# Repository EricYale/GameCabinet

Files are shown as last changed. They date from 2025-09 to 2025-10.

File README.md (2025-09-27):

# GameCabinet
Raspberry Pi game cabinet, made for CPSC 3340 Creative Embedded Systems

## Required Materials
- [Raspberry Pi Zero 2 W, headerless](https://a.co/d/8KMoVYZ)
- [ESP-WROOM-32](https://a.co/d/iZ32vMO)
- SD card
- [Small touchscreen for Raspberry Pi Zero](https://a.co/d/8ljvQEd)
- [Short MtM microUSB cable](https://a.co/d/d5F0nlR)
- [Breadboard-layout PCBs](https://a.co/d/15BTbv4)
- [Joystick](https://a.co/d/iXG2HW7) (x2)
- Push button (x2)
- Flip switch (x2)

## Electronics Instructions

### Display

First, you have to solder your RasPi Zero to the small display. Solder all the pins; I found that it's much easier if you create an electrical connection between the pins and the holes before soldering by bending them slightly so they touch the copper rings. This makes it so that both the pins and the holes get heated and the solder can flow between them.

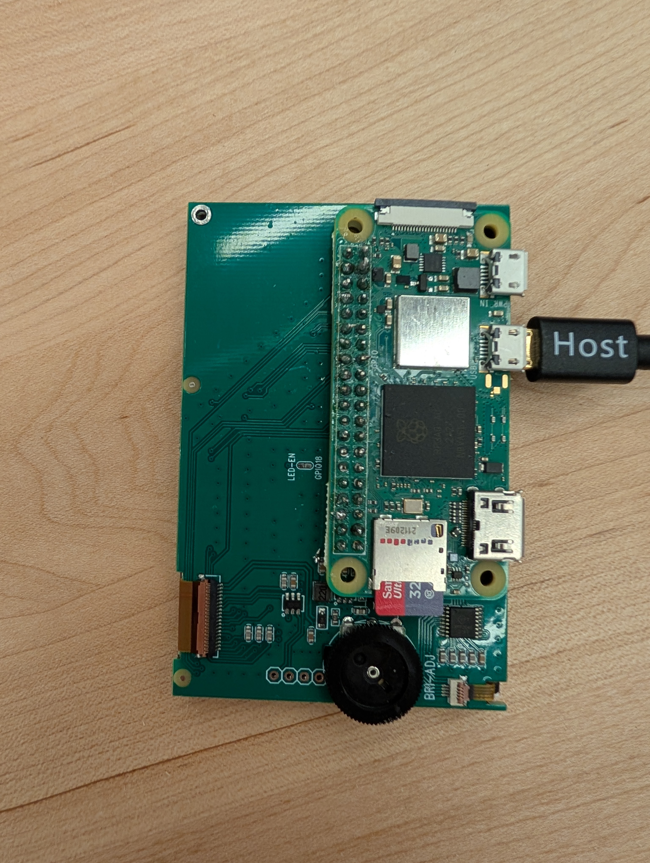
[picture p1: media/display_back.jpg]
Display solder


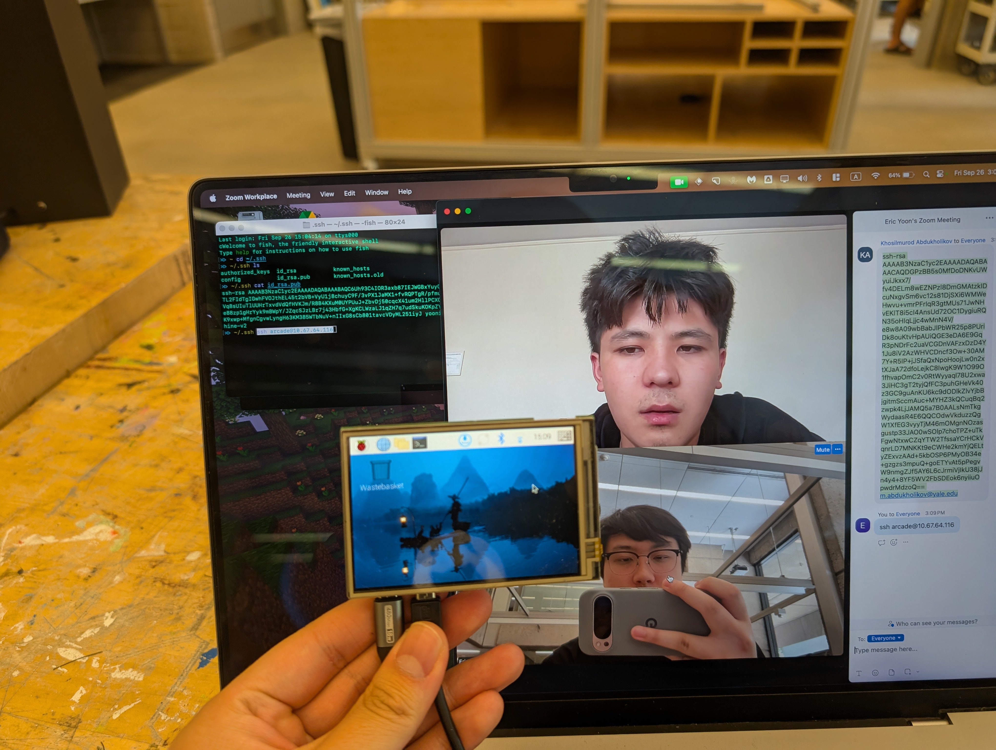
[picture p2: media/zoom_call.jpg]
Murad on Zoom


### Joystick
The joysticks you can get on Amazon come pre-installed with MtM headers. We need to remove these.

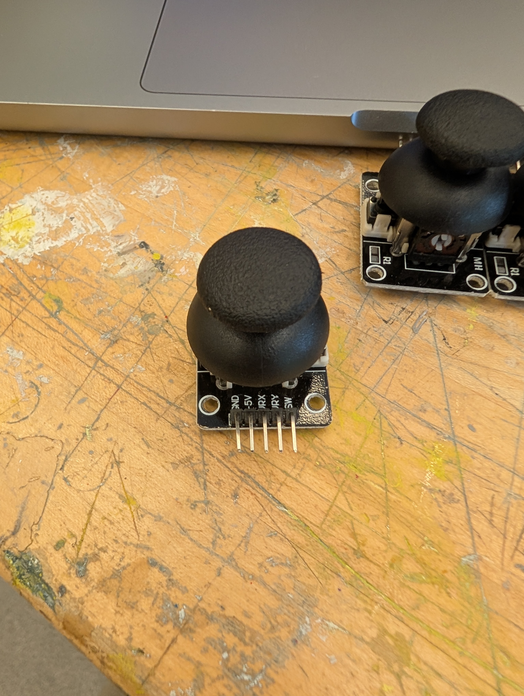
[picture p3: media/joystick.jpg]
Joystick headers that we need to remove


The best way to do this is to separate the headers by crushing them with some piliers, then applying heat and pulling them out one by one. Note that if you apply heat while pulling with the pliers, the pliers will act as a heat sink, so apply heat *then* apply pliers.

Then, you can solder your own wires to each of the four pins to be used: `GND`, `5V`, `VRY`, and `VRX`. Make sure to use long enough wires.

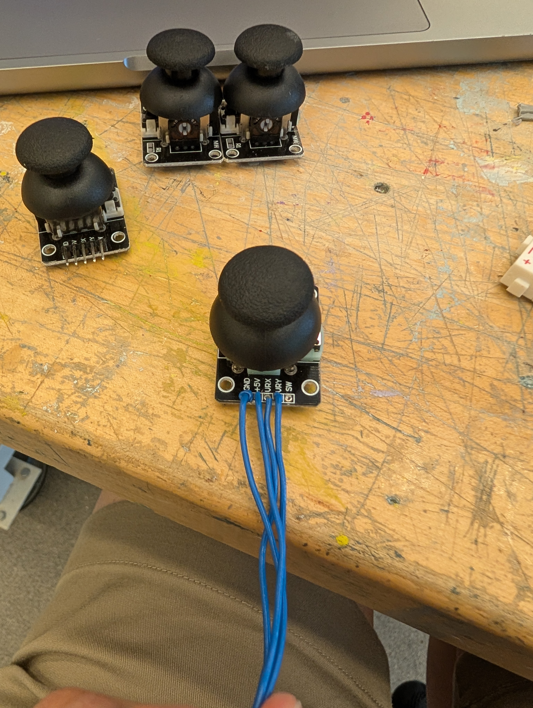
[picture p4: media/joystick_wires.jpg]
Joystick with wires


## 3D Printing Instructions

OnShape CAD available [here](https://cad.onshape.com/documents/6f27eda065649b08f7d7cace/w/1f5f86e878a776f90a9c0eb1/e/d24df1ab04ee5fd927d72df8).

Also see STL files in `/cad`

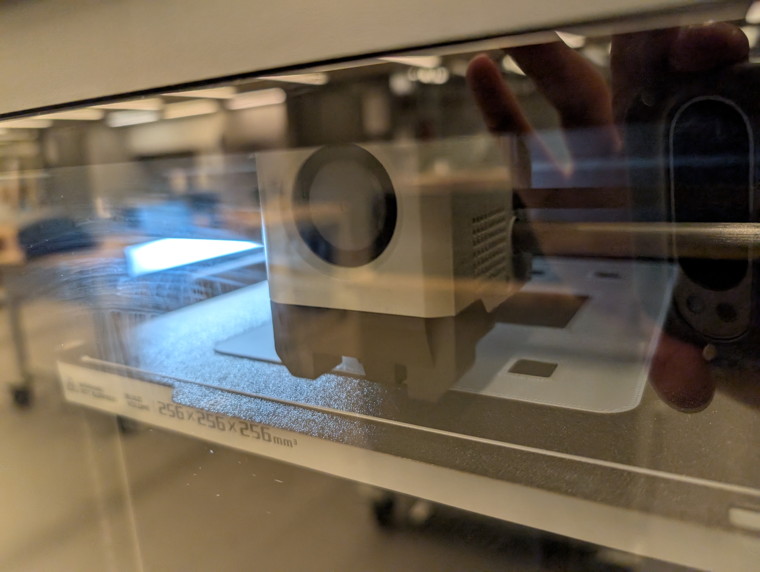
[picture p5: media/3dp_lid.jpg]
3D print in progress


## Pi Setup Instructions

Follow [this guide](https://www.raspberrypi.com/documentation/computers/getting-started.html) to install boot media onto an SD card for Raspberry Pi Zero.

On the SD card, follow [manufacturer's instructions](https://github.com/iUniker/Pi-Zero-3.5-Inch-Screen/tree/main) to add the drivers to the Pi, so it displays to the screen upon bootup.

At this point, you can boot up the Pi; if you need to register your device on the Yale network you can get the MAC address by doing `ifconfig`.

Once the Pi is connected to the Internet, you can get the IP address, SSH in, and add your SSH key.

You can then clone this repo, set Git to store your credentials, and log in with a Personal Access Token.

I also recommend adding an authorized SSH key.

## Technical Details

Sensor data is sent from the ESP32 to the Raspberry Pi over USB serial. Right now, data is being sent as ASCII (although in the future we could change this to raw binary data).

```
2048/2048/2048/2048/1/1/0/0
```
Where the numbers are delimited by slash (`/`). Each number represents:

1. Player 1 joystick X
2. Player 1 joystick Y
3. Player 2 joystick X
4. Player 2 joystick Y
5. Player 1 button
6. Player 2 button
7. Player 1 switch
8. Player 2 switch

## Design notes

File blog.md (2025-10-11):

# Game Cabinet

Demos:

[Gravity Game video](./media/space.mp4)

[Plant Growth video](./media/plant.mov)

[Asteroids video](./media/play_together.mov)

## **Creative Vision**

The initial concept was to create generative art pieces inspired by classic arcade games. That’s how we came up with **GameCabinet**, a two-player interactive box that can be used for collaborative art generation and playing games.

Two players sit facing each other with a small central display between them. Each has a joystick, a button, and a toggle switch. When connected via USB, the arcade menu loads and presents three modes: *Asteroids*, a collaborative *Plant Growth* simulation, and a shared *Gravity Planet* environment.

- **Asteroids**: a clone of the classic arcade game, as a proof-of-concept of how the form factor can be used for all sorts of games.
- **Plant Growth:** In this mode, two players collaborate to shape the direction, the buddings, and the flowers in a plant through the controls. Each play session results in a unique creation.
- **Gravity Planet:** Players collaborate to simulate asteroids forming rings around the two planets. Joysticks are used to generate asteroids, while with the buttons, the gravity of the two planets can be adjusted.

---

## **Technical Overview**

For the project, Eric bought a **Raspberry Pi Zero 2 W** and a **mini-screen.** **Raspberry Pi Zero 2 W** serves as the main compute module; while it has less computing power, its small form factor makes it ideal for this project. It connects via USB serial to an **ESP-WROOM-32 microcontroller**, which reads all sensor data from the input hardware and transmits it to the Pi via serial.

### **Hardware Components**

Each player’s control panel includes:

- Analog joystick
- Push button
- Toggle switch

Additional components:

- Pi Zero Display Shield
- ESP32

On the Pi, the application parses data from the inputs and converts them into real-time logic for interaction.

---

## Hardware Details

We decided to solder each component onto a protoboard so the device could handle light impacts (from being carried around in a backpack, lightly battered when one player rage-quits, etc). Some steps in the process of fabricating the electronics:

1. Every pin on the RasPi Zero W was soldered directly onto the pins of the mini display.
2. Pre-installed male headers were removed from the joysticks, and wires were soldered on.
3. Input peripherals and ESP32 were soldered to proto board.

You can view more detailed instructions for making your own Game Cabinet [in our README](./README.md).

## Enclosure

The enclosure was designed in OnShape and 3D printed. To facilitate easy modeling, we were able to find models of our standard components (joystick, switch, button) online; we imported these models and designed around their dimensions. Some iteration was still necessary, but we were able to get a satisfactory enclosure fabricated in just 2 print jobs.

STL files are included in [here](./cad/).

---

## **Modes of Interaction**

As mentioned above, we implemented three interaction modes that the user can select from the Arcade Menu.

### **1. Asteroids**

This mode recreates the classic asteroids game in the arcade box.

- each joystick controls a spaceship’s movement on screen.
- button presses fire projectiles to destroy incoming asteroids.
- switches toggle thrusts the spaceship.

### **2. Growth**

The **Growth** game is a collaborative, rather than competitive, experience. It’s supposed to encourage communication between players while creating a zen atmosphere. When you’re done playing, you can pause and enjoy the ephemeral and unique creation you’ve made with your partner.

- the collaborative joystick positions determine the direction that the plant grows. Players need to be on the same page about which direction they want to go!
- button presses either creates buds (P1), or adds flowers (P2)
- switches either pause or resume the game. Both players need to agree to resume the game for the simulation to tick.

As the plant keeps growing, the earlier trunk of the plant keeps getting thicker. After the plant goes out of the screen, the earliest bud starts growing. The buds are added to the FIFO stack.

### 3. Gravity Planet

This mode explores how two players acting independently can lead to emergent behavior; and how when those two players collaborate, they can achieve even more complex behavior. We were inspired by classic physics-based games and simulations. We expect players to find fascination in our simulation and organically come up with goals (make all the balls travel in a perfect ellipse, etc). To do this, though, they have to communicate with their partner across the device.

## **Challenges & Solutions**

- **Programming:** We *vibecoded* the modes together. Because the Raspberry Pi Zero’s performance was limited, we couldn’t program directly on the Pi. Instead, we’d write code locally, push it to Git, and then hope it ran correctly after each commit. Luckily, we were able to run the simulations on our laptops before pushing code to the Pi, albeit with keyboard/mouse input rather than control surface input. The LLM originally had lots of trouble conceptualizing our serial communication; to alleviate this, we wrote an LLMS.md file along with hand-written ESP32 deserialization example code.
- **Analog Input on Digital Hardware:** The Raspberry Pi’s GPIO pins can’t read analog signals directly, so we offloaded sensor reading to the ESP32, which forwards processed data over serial.

Below are some of the photos from the process of completing the project.

3D printed lid

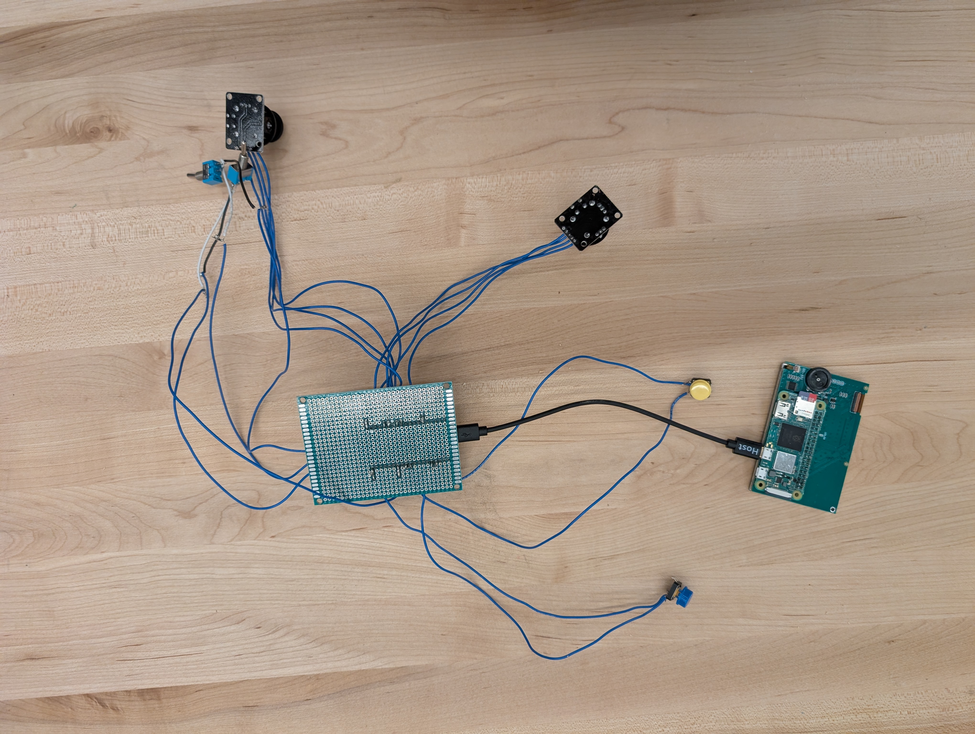
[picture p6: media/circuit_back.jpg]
Circuit back


Display back

Joystick

Joystick wires

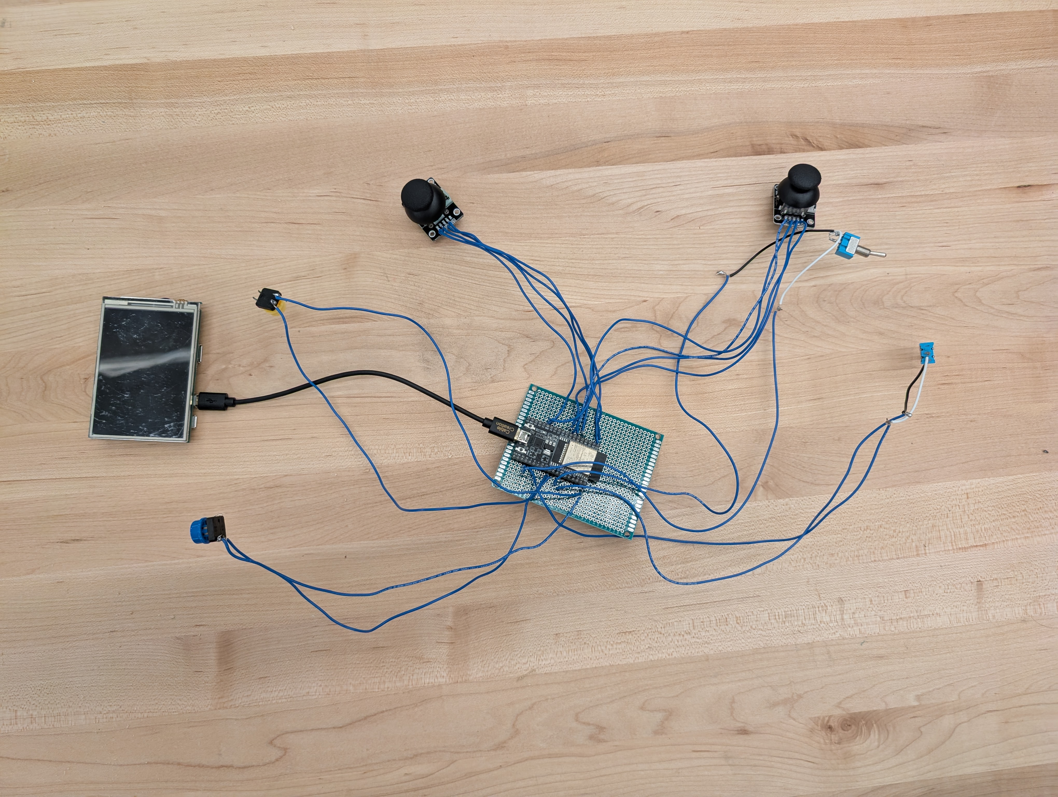
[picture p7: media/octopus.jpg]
Octopus


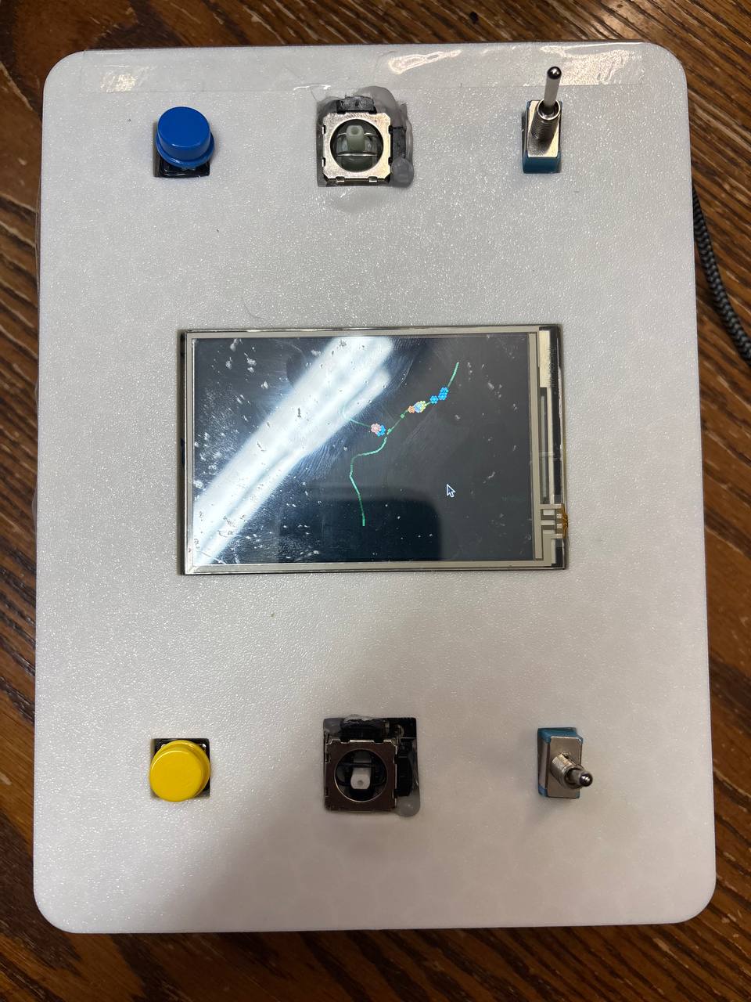
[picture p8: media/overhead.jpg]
Overhead


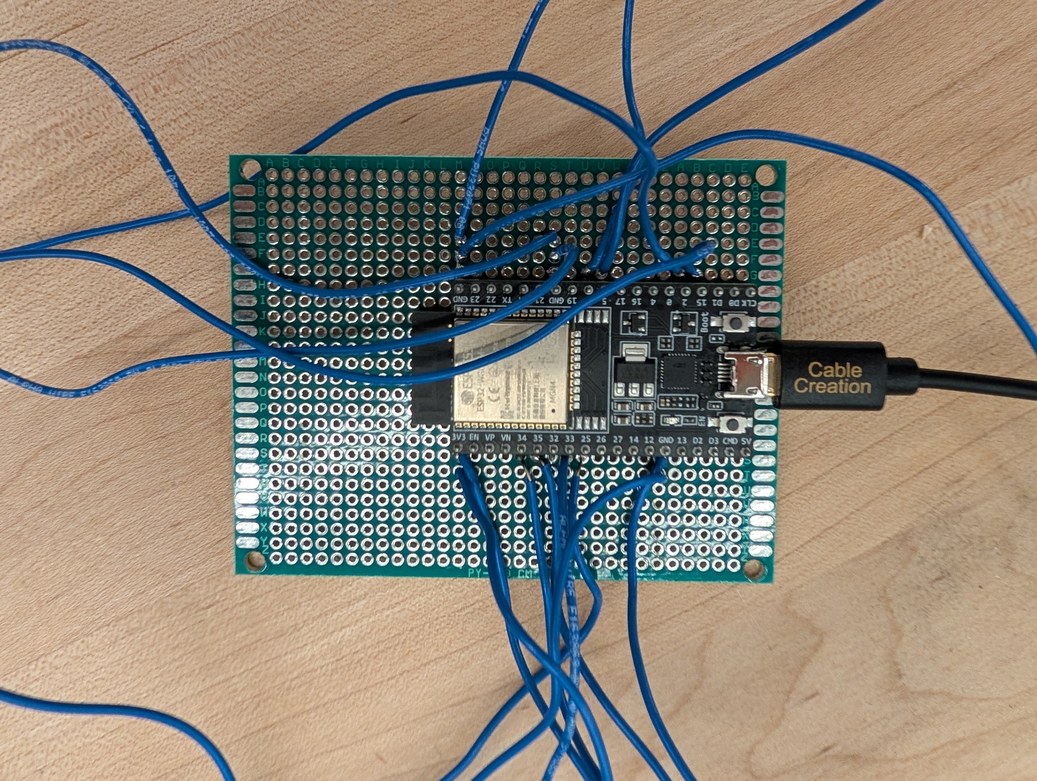
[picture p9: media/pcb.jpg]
PCB


Zoom call

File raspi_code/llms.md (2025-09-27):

# Notes to LLMs

You are writing code for a physical embedded system. The embedded system is running on a Raspberry Pi Zero 2 W, connected via USB to an ESP32, which reads sensor data and sends it using serial to the Raspberry Pi.

The device looks like a mini arcade cabinet, where two players sit facing each other, with the device in the middle. Each player has a joystick (X and Y axis), a momentary push button, and a toggle switch. There is a screen in the middle of the arcade cabinet which both players will look at; this means it's important to make sure any graphics are orientation-agnostic (so it's not upside down for one player).

The ESP32 communicates to the Raspberry Pi via serial. It sends numbers (which are ASCII strings and need to be parsed to ints). These numbers are slash-deliminated like so:

```
2048/2048/2048/2048/1/1/0/0
```
Each number represents:

1. Player 2 joystick Y (NOTE: this is inoperative, so your program must not use this input)
2. Player 2 joystick X
3. Player 1 joystick Y (NOTE: this is inoperative, so your program must not use this input)
4. Player 1 joystick X
5. Player 1 button (1 for unpressed, 0 for pressed)
6. Player 2 button (1 for unpressed, 0 for pressed)
7. Player 1 switch (0 for DOWN, 1 for UP)
8. Player 2 switch (1 for DOWN, 0 for UP; note that this is reverse of P1)

Your task is to code the game or application that I specify. You can view a demo of parsing the serial data from the ESP32 in esp32_input_demo.py. Your game should run full-screen on the Raspberry Pi when I start the program with `python3 <...>.py`. Please use pygame for your game; assume that the dependency is already installed.

At the top of your file, write down a high-level overview (2 paragraphs) of the game I described, and any implementation details that are not already specified in llms.md. Please do not leave any other comments in the code, because I am very good at reading code without comments.

Do not run any terminal commands to install packages; I will do these manually. Also please work ONLY in the file I specify. Do not create any python virtual environments.

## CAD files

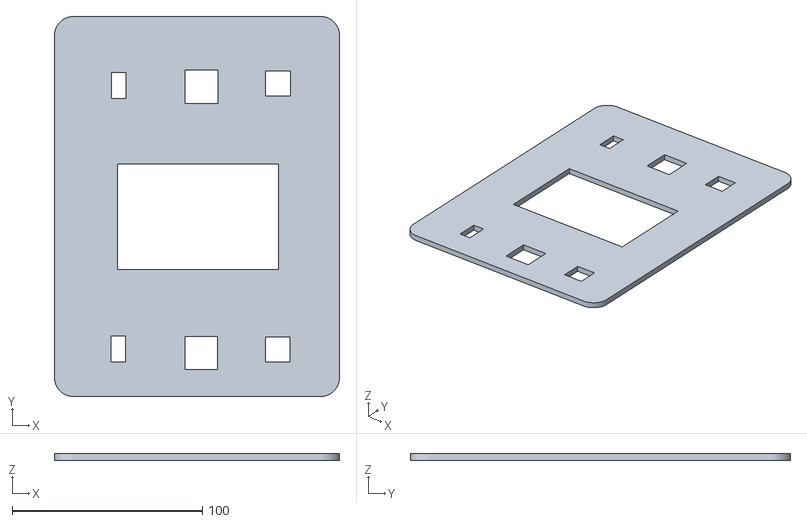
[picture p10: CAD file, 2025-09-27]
cad/lid.stl
150.0 x 200.0 x 3.50

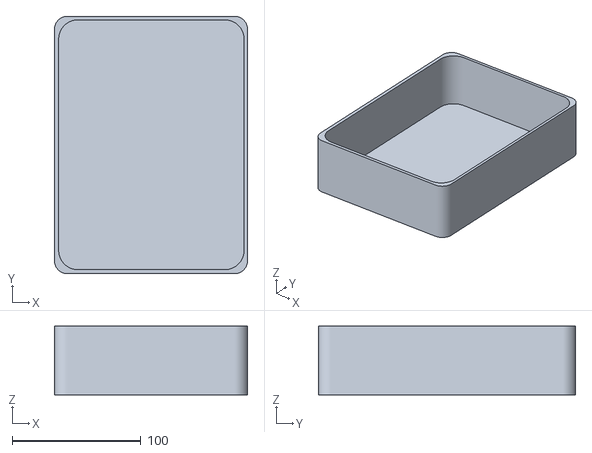
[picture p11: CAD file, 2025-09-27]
cad/housing.stl
150.0 x 200.0 x 53.5

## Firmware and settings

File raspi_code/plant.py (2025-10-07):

# Symbiosis Garden is a meditative cooperative art experience where two players
# nurture a shared digital plant through synchronized interaction. Players use
# their joysticks to collectively guide the plant's growth direction - when both
# players point in similar directions, the plant grows that way, but if they
# disagree, the plant pauses until they find harmony. This creates a natural
# dialogue through movement. The buttons allow players to add colorful flowers
# along the plant's stem, while the toggle switches control the growth state -
# both players must agree to grow (switches up) or rest (switches down).

# The implementation uses particle systems for organic, flowing growth patterns
# and a color palette that shifts based on the players' harmony level. The plant
# grows as a series of connected segments, each influenced by the average joystick
# input when there's agreement. Flowers bloom as animated sprites at button press
# locations, with colors cycling through a natural spectrum. The background
# subtly shifts to reflect the garden's health and the players' collaboration,
# creating a living, breathing digital ecosystem that responds to human connection.

import pygame
import serial
import math
import random
import time

pygame.init()

# Colors
DEEP_GREEN = (20, 60, 30)
SOFT_GREEN = (50, 120, 60)
BRIGHT_GREEN = (80, 200, 100)
FLOWER_COLORS = [
    (255, 100, 150),  # Pink
    (255, 200, 50),   # Yellow
    (150, 100, 255),  # Purple
    (255, 150, 100),  # Orange
    (100, 200, 255),  # Blue
    (255, 255, 150),  # Light Yellow
]
STEM_COLOR = (60, 140, 80)
BACKGROUND_BASE = (15, 25, 20)

# Screen setup
info = pygame.display.Info()
SCREEN_WIDTH, SCREEN_HEIGHT = info.current_w, info.current_h
SCALE_FACTOR = min(SCREEN_WIDTH / 1280.0, 1.0)
screen = pygame.display.set_mode((SCREEN_WIDTH, SCREEN_HEIGHT), pygame.FULLSCREEN)
pygame.display.set_caption("Symbiosis Garden")

# Serial setup
try:
    ser = serial.Serial("/dev/ttyUSB0", 115200, timeout=0.01)
except serial.SerialException:
    ser = None
    print("Serial port not found. Running with keyboard controls.")

class PlantSegment:
    def __init__(self, x, y, angle, length, base_thickness=None):
        self.start_pos = pygame.Vector2(x, y)
        self.angle = angle
        self.length = length
        self.end_pos = self.start_pos + pygame.Vector2(
            math.cos(math.radians(angle)) * length,
            math.sin(math.radians(angle)) * length
        )
        self.base_thickness = base_thickness if base_thickness else 8 * SCALE_FACTOR
        self.thickness = self.base_thickness
        self.age = 0
        self.growth_animation = 0
        self.segment_index = 0
        
    def update(self, dt):
        self.age += dt
        if self.growth_animation < 1.0:
            self.growth_animation = min(1.0, self.growth_animation + dt * 2)
            
    def update_thickness(self, total_segments):
        # Older segments (lower index) get thicker as plant grows
        age_factor = max(0.5, 1.0 - (self.segment_index / max(1, total_segments)))
        thickness_boost = (total_segments - self.segment_index) * 0.5 * SCALE_FACTOR
        self.thickness = self.base_thickness + thickness_boost * age_factor
            
    def draw(self, surface):
        if self.growth_animation <= 0:
            return
            
        current_length = self.length * self.growth_animation
        current_end = self.start_pos + pygame.Vector2(
            math.cos(math.radians(self.angle)) * current_length,
            math.sin(math.radians(self.angle)) * current_length
        )
        
        # Draw segment with slight transparency for organic feel
        color_intensity = 200 + int(55 * math.sin(self.age * 0.5))
        color = (
            max(0, min(255, STEM_COLOR[0] + color_intensity - 200)),
            max(0, min(255, STEM_COLOR[1] + color_intensity - 200)),
            max(0, min(255, STEM_COLOR[2] + color_intensity - 200))
        )
        
        pygame.draw.line(surface, color, self.start_pos, current_end, int(self.thickness))

class Flower:
    def __init__(self, x, y, color):
        self.pos = pygame.Vector2(x, y)
        self.color = color
        self.size = 0
        self.max_size = random.uniform(15, 25) * SCALE_FACTOR
        self.bloom_speed = random.uniform(3, 5)
        self.sway_offset = random.uniform(0, math.pi * 2)
        self.age = 0
        self.petals = random.randint(5, 8)
        
    def update(self, dt):
        self.age += dt
        if self.size < self.max_size:
            self.size = min(self.max_size, self.size + self.bloom_speed * dt)
            
    def draw(self, surface):
        if self.size <= 0:
            return
            
        # Gentle swaying
        sway = math.sin(self.age * 2 + self.sway_offset) * 2
        current_pos = self.pos + pygame.Vector2(sway, 0)
        
        # Draw petals
        for i in range(self.petals):
            angle = (i / self.petals) * 2 * math.pi
            petal_pos = current_pos + pygame.Vector2(
                math.cos(angle) * self.size * 0.6,
                math.sin(angle) * self.size * 0.6
            )
            pygame.draw.circle(surface, self.color, petal_pos, int(self.size * 0.4))
            
        # Draw center
        center_color = tuple(max(0, min(255, c + 50)) for c in self.color)
        pygame.draw.circle(surface, center_color, current_pos, int(self.size * 0.3))

class Bud:
    def __init__(self, x, y, segment_index):
        self.pos = pygame.Vector2(x, y)
        self.segment_index = segment_index
        self.size = 0
        self.max_size = 8 * SCALE_FACTOR
        self.growth_speed = 4
        self.age = 0
        self.used = False
        self.pulse_offset = random.uniform(0, math.pi * 2)
        
    def update(self, dt):
        self.age += dt
        if self.size < self.max_size and not self.used:
            self.size = min(self.max_size, self.size + self.growth_speed * dt)
            
    def draw(self, surface):
        if self.size <= 0:
            return
            
        # Pulsing green bud
        pulse = 0.8 + 0.2 * math.sin(self.age * 3 + self.pulse_offset)
        if self.used:
            pulse *= 0.3  # Dim when used
            
        bud_color = tuple(int(c * pulse) for c in BRIGHT_GREEN)
        pygame.draw.circle(surface, bud_color, self.pos, int(self.size))
        
        # Small highlight
        highlight_pos = self.pos + pygame.Vector2(-2, -2)
        highlight_color = tuple(min(255, int(c * 1.5)) for c in bud_color)
        pygame.draw.circle(surface, highlight_color, highlight_pos, int(self.size * 0.4))

class HarmonyParticle:
    def __init__(self, x, y):
        self.pos = pygame.Vector2(x, y)
        self.vel = pygame.Vector2(
            random.uniform(-50, 50) * SCALE_FACTOR,
            random.uniform(-100, -20) * SCALE_FACTOR
        )
        self.life = 1.0
        self.decay_rate = random.uniform(0.5, 1.0)
        self.size = random.uniform(2, 6) * SCALE_FACTOR
        
    def update(self, dt):
        self.pos += self.vel * dt
        self.life -= self.decay_rate * dt
        self.vel.y += 20 * dt  # Slight gravity
        
    def draw(self, surface):
        if self.life <= 0:
            return
        alpha = int(255 * self.life)
        color = (*BRIGHT_GREEN, alpha)
        
        # Create surface with per-pixel alpha
        particle_surf = pygame.Surface((int(self.size * 2), int(self.size * 2)), pygame.SRCALPHA)
        pygame.draw.circle(particle_surf, color, (int(self.size), int(self.size)), int(self.size))
        surface.blit(particle_surf, (self.pos.x - self.size, self.pos.y - self.size), special_flags=pygame.BLEND_ALPHA_SDL2)

def calculate_joystick_direction_and_speed(p1_x, p2_x):
    """Calculate growth direction and speed from average joystick input"""
    # Convert to -1 to 1 range
    p1_normalized = (p1_x - 2048) / 2048.0
    p2_normalized = (p2_x - 2048) / 2048.0
    
    # Calculate average direction
    avg_direction = (p1_normalized + p2_normalized) / 2
    
    # Speed based on magnitude of average direction
    speed = abs(avg_direction)
    
    # Direction in degrees (convert from -1,1 to angle change)
    angle_change = avg_direction * 45  # Max 45 degrees per growth step
    
    return angle_change, speed

def main():
    clock = pygame.time.Clock()
    running = True
    last_time = time.time()
    
    # Plant state
    plant_segments = []
    flowers = []
    buds = []
    harmony_particles = []
    current_growth_point = None  # Tracks where we're currently growing from
    
    # Growth parameters
    plant_base_x = SCREEN_WIDTH // 2
    plant_base_y = SCREEN_HEIGHT - 100 * SCALE_FACTOR
    current_angle = -90  # Start growing upward
    segment_length = 25 * SCALE_FACTOR
    
    # Game state
    growth_active = False
    background_pulse = 0.0
    growth_frame_counter = 0
    frames_per_growth = 5  # Grow every 5 frames for slower growth
    
    # Input states
    p1_button_pressed = False
    p2_button_pressed = False
    p1_switch_state = 0
    p2_switch_state = 1
    
    # Add initial root segment
    root_segment = PlantSegment(plant_base_x, plant_base_y, current_angle, segment_length)
    root_segment.growth_animation = 1.0
    root_segment.segment_index = 0
    plant_segments.append(root_segment)
    current_growth_point = root_segment
    
    while running:
        current_time = time.time()
        dt = current_time - last_time
        last_time = current_time
        
        # Handle events
        for event in pygame.event.get():
            if event.type == pygame.QUIT:
                running = False
            if event.type == pygame.KEYDOWN:
                if event.key == pygame.K_ESCAPE:
                    running = False
        
        # Read serial input
        p1_joy_x, p2_joy_x = 2048, 2048  # Default neutral
        p1_button, p2_button = 1, 1      # Default unpressed
        p1_switch, p2_switch = 0, 1      # Default states
        
        if ser:
            while ser.in_waiting:
                try:
                    line = ser.readline().decode('utf-8').rstrip()
                    if line:
                        values = line.split("/")
                        if len(values) == 8:
                            p1_joy_x = int(values[1])
                            p2_joy_x = int(values[3])
                            p1_button = int(values[4])
                            p2_button = int(values[5])
                            p1_switch = int(values[6])
                            p2_switch = int(values[7])
                except (ValueError, IndexError):
                    pass
        else:
            # Keyboard fallback for testing
            keys = pygame.key.get_pressed()
            # More responsive keyboard controls
            if keys[pygame.K_a]: p1_joy_x = 500   # Left
            if keys[pygame.K_d]: p1_joy_x = 3500  # Right
            if keys[pygame.K_LEFT]: p2_joy_x = 500   # Left
            if keys[pygame.K_RIGHT]: p2_joy_x = 3500 # Right
            if keys[pygame.K_SPACE]: p1_button = 0
            if keys[pygame.K_RETURN]: p2_button = 0
        
        # Calculate joystick direction and speed from average
        angle_change, growth_speed = calculate_joystick_direction_and_speed(p1_joy_x, p2_joy_x)
        
        # Check if both players have switches in grow position
        # P1 switch: 1 = UP (grow), 0 = DOWN (pause)
        # P2 switch: 0 = UP (grow), 1 = DOWN (pause) - reversed!
        growth_active = (p1_switch == 1 and p2_switch == 0)
        
        # Handle differentiated button functions
        if plant_segments:
            tip_segment = plant_segments[-1]
            tip_pos = tip_segment.end_pos
            
            # Player 1: Plant flowers
            if p1_button == 0 and not p1_button_pressed:
                color = random.choice(FLOWER_COLORS)
                flowers.append(Flower(tip_pos.x, tip_pos.y, color))
                # Add harmony particles
                for _ in range(5):
                    harmony_particles.append(HarmonyParticle(tip_pos.x, tip_pos.y))
                p1_button_pressed = True
            elif p1_button == 1:
                p1_button_pressed = False
                
            # Player 2: Create buds (new growth points)
            if p2_button == 0 and not p2_button_pressed:
                # Place bud at current tip location, but it will become a branch point
                bud = Bud(tip_pos.x, tip_pos.y, len(plant_segments) - 1)
                buds.append(bud)
                # Add harmony particles
                for _ in range(3):
                    harmony_particles.append(HarmonyParticle(tip_pos.x, tip_pos.y))
                p2_button_pressed = True
            elif p2_button == 1:
                p2_button_pressed = False
        
        # SIMPLE GROWTH: Grow with joystick direction (only if growth_active)
        if growth_active:
            growth_frame_counter += 1
            if growth_frame_counter % frames_per_growth == 0:
                # Apply joystick direction change
                test_angle = current_angle + angle_change
                test_angle = max(-160, min(160, test_angle))
                
                # Calculate where the next segment would end up
                next_end_x = current_growth_point.end_pos.x + math.cos(math.radians(test_angle)) * segment_length
                next_end_y = current_growth_point.end_pos.y + math.sin(math.radians(test_angle)) * segment_length
                
                # Check if next segment would go out of bounds
                margin = 50
                would_hit_edge = (next_end_x < margin or next_end_x > SCREEN_WIDTH - margin or 
                                 next_end_y < margin or next_end_y > SCREEN_HEIGHT - margin)
                
                if would_hit_edge:
                    # Hit edge - try to branch to a bud if available
                    if buds:
                        next_bud = None
                        for bud in buds:
                            if not bud.used:
                                next_bud = bud
                                break
                        
                        if next_bud:
                            # Branch to this bud
                            next_bud.used = True
                            current_growth_point = plant_segments[next_bud.segment_index]
                            current_angle = -45
                            
                            new_segment = PlantSegment(
                                next_bud.pos.x,
                                next_bud.pos.y,
                                current_angle,
                                segment_length,
                                base_thickness=6 * SCALE_FACTOR
                            )
                            new_segment.segment_index = len(plant_segments)
                            plant_segments.append(new_segment)
                            current_growth_point = new_segment
                            
                            for _ in range(5):
                                harmony_particles.append(HarmonyParticle(next_bud.pos.x, next_bud.pos.y))
                    # If no buds, just stop growing (don't add segment)
                else:
                    # Not hitting edge - grow normally
                    current_angle = test_angle
                    
                    new_segment = PlantSegment(
                        current_growth_point.end_pos.x,
                        current_growth_point.end_pos.y,
                        current_angle,
                        segment_length
                    )
                    new_segment.segment_index = len(plant_segments)
                    plant_segments.append(new_segment)
                    current_growth_point = new_segment
                    
                    for _ in range(3):
                        harmony_particles.append(HarmonyParticle(
                            current_growth_point.end_pos.x, current_growth_point.end_pos.y
                        ))
        
        # Update all objects
        for i, segment in enumerate(plant_segments):
            segment.update(dt)
            segment.update_thickness(len(plant_segments))
        
        for flower in flowers:
            flower.update(dt)
            
        for bud in buds:
            bud.update(dt)
        
        harmony_particles = [p for p in harmony_particles if p.life > 0]
        for particle in harmony_particles:
            particle.update(dt)
        
        # Update background pulse
        background_pulse += dt
        
        # Render
        # Dynamic background based on growth activity
        pulse_intensity = int(10 * growth_speed * (1 + math.sin(background_pulse * 2) * 0.3)) if growth_active else 0
        bg_color = tuple(max(0, min(255, c + pulse_intensity)) for c in BACKGROUND_BASE)
        screen.fill(bg_color)
        
        # Draw plant segments
        for segment in plant_segments:
            segment.draw(screen)
        
        # Draw flowers
        for flower in flowers:
            flower.draw(screen)
            
        # Draw buds
        for bud in buds:
            bud.draw(screen)
        
        # Draw harmony particles
        for particle in harmony_particles:
            particle.draw(screen)
        
        # Draw growth indicator (subtle glow around current growth point)
        if current_growth_point and growth_active and growth_speed > 0.1:
            tip = current_growth_point.end_pos
            glow_radius = int(30 * growth_speed * SCALE_FACTOR)
            glow_alpha = int(50 * growth_speed)
            
            glow_surf = pygame.Surface((glow_radius * 2, glow_radius * 2), pygame.SRCALPHA)
            glow_color = (*BRIGHT_GREEN, glow_alpha)
            pygame.draw.circle(glow_surf, glow_color, (glow_radius, glow_radius), glow_radius)
            screen.blit(glow_surf, (tip.x - glow_radius, tip.y - glow_radius), 
                       special_flags=pygame.BLEND_ALPHA_SDL2)
        
        # Draw growth status indicators in corners
        status_radius = 10 * SCALE_FACTOR
        # Player 1 indicator (bottom left)
        p1_color = BRIGHT_GREEN if (p1_switch == 1) else (100, 100, 100)
        pygame.draw.circle(screen, p1_color, 
                         (int(30 * SCALE_FACTOR), int(SCREEN_HEIGHT - 30 * SCALE_FACTOR)), 
                         int(status_radius))
        
        # Player 2 indicator (bottom right)  
        p2_color = BRIGHT_GREEN if (p2_switch == 0) else (100, 100, 100)
        pygame.draw.circle(screen, p2_color, 
                         (int(SCREEN_WIDTH - 30 * SCALE_FACTOR), int(SCREEN_HEIGHT - 30 * SCALE_FACTOR)), 
                         int(status_radius))
        
        pygame.display.flip()
        clock.tick(60)
    
    pygame.quit()

if __name__ == '__main__':
    main()

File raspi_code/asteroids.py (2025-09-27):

# This game is a two-player version of the classic arcade game "Asteroids,"
# designed for a custom-built mini arcade cabinet. Two players control their
# respective ships on a single screen, viewed from opposite sides. The objective
# is to survive as long as possible by shooting asteroids and the opponent's
# ship. Each player has a joystick for rotation, a button for shooting, and a
# toggle switch to control acceleration. The game uses simple vector graphics
# to represent ships, asteroids, and bullets, staying true to the original's
# aesthetic and ensuring the display is clear for both players regardless of
# their orientation.

# The game is implemented in Python using the Pygame library for graphics and
# event handling. It reads player inputs from an ESP32 microcontroller via a
# serial connection. The serial data, a slash-delimited string of sensor
# values, is parsed to control each player's ship. The game features wrap-around
# screen space, so objects leaving one edge of the screen reappear on the
# opposite side. Player lives are displayed as dots on the left and right edges
# of the screen. The game state, including positions and velocities of all
# objects, is updated in a main loop that also handles rendering and input
# processing. All motion is made framerate-independent through the use of
# a delta-time (dt) value in physics calculations.

import pygame
import serial
import math
import random
import time

pygame.init()

BLACK = (0, 0, 0)
WHITE = (255, 255, 255)
RED = (255, 0, 0)
BLUE = (0, 0, 255)

info = pygame.display.Info()
SCREEN_WIDTH, SCREEN_HEIGHT = info.current_w, info.current_h
SCALE_FACTOR = min(SCREEN_WIDTH / 1280.0, 1.0) # Cap at 1.0 for screens larger than reference
screen = pygame.display.set_mode((SCREEN_WIDTH, SCREEN_HEIGHT), pygame.FULLSCREEN)
pygame.display.set_caption("Asteroids")
font = pygame.font.Font(None, int(74 * SCALE_FACTOR))
small_font = pygame.font.Font(None, int(50 * SCALE_FACTOR))

try:
    ser = serial.Serial("/dev/ttyUSB0", 115200, timeout=0.01)
except serial.SerialException:
    ser = None
    print("Serial port not found. Running with keyboard controls.")

class Ship:
    def __init__(self, x, y, color, player_id):
        self.player_id = player_id
        self.pos = pygame.Vector2(x, y)
        self.vel = pygame.Vector2(0, 0)
        self.angle = 0
        self.color = color
        self.radius = 20 * SCALE_FACTOR
        self.lives = 5
        self.is_accelerating = False
        self.turn_direction = 0
        self.last_shot_time = 0
        self.shoot_cooldown = 0.25
        self.respawn_time = 0
        self.invincible = False
        self.acceleration_rate = 200 * SCALE_FACTOR
        self.turn_rate = 150
        self.damping = 0.5

    def draw(self, surface):
        if self.lives <= 0 or self.is_respawning():
            return

        if self.invincible and (pygame.time.get_ticks() // 200) % 2 == 0:
            return

        draw_radius = 30 * SCALE_FACTOR
        point1 = self.pos + pygame.Vector2(math.cos(math.radians(self.angle)), math.sin(math.radians(self.angle))) * draw_radius
        point2 = self.pos + pygame.Vector2(math.cos(math.radians(self.angle + 140)), math.sin(math.radians(self.angle + 140))) * draw_radius
        point3 = self.pos + pygame.Vector2(math.cos(math.radians(self.angle - 140)), math.sin(math.radians(self.angle - 140))) * draw_radius
        pygame.draw.polygon(surface, self.color, [point1, point2, point3], 2)

    def update(self, dt):
        self.angle += self.turn_direction * self.turn_rate * dt

        if self.is_accelerating:
            acceleration = pygame.Vector2(math.cos(math.radians(self.angle)), math.sin(math.radians(self.angle))) * self.acceleration_rate
            self.vel += acceleration * dt
        
        self.vel -= self.vel * self.damping * dt
        self.pos += self.vel * dt

        self.pos.x %= SCREEN_WIDTH
        self.pos.y %= SCREEN_HEIGHT

        if self.invincible and pygame.time.get_ticks() > self.respawn_time + 3000:
            self.invincible = False

        if self.is_respawning():
            self.vel = pygame.Vector2(0, 0)

    def shoot(self, bullets):
        current_time = time.time()
        if self.lives > 0 and not self.is_respawning() and current_time - self.last_shot_time > self.shoot_cooldown:
            self.last_shot_time = current_time
            bullet_vel = self.vel + pygame.Vector2(math.cos(math.radians(self.angle)), math.sin(math.radians(self.angle))) * 300 * SCALE_FACTOR
            bullets.append(Bullet(self.pos, bullet_vel, self.player_id))

    def hit(self):
        if not self.invincible:
            self.lives -= 1
            if self.lives > 0:
                self.respawn()
            return True
        return False

    def respawn(self):
        self.pos = pygame.Vector2(SCREEN_WIDTH // 4 if self.player_id == 1 else 3 * SCREEN_WIDTH // 4, SCREEN_HEIGHT // 2)
        self.vel = pygame.Vector2(0, 0)
        self.angle = 0
        self.respawn_time = pygame.time.get_ticks()
        self.invincible = True

    def is_respawning(self):
        return self.invincible and pygame.time.get_ticks() < self.respawn_time + 3000

class Bullet:
    def __init__(self, pos, vel, owner_id):
        self.pos = pygame.Vector2(pos)
        self.vel = pygame.Vector2(vel)
        self.radius = 3 * SCALE_FACTOR
        self.lifespan = 2.5
        self.birth_time = time.time()
        self.owner_id = owner_id

    def draw(self, surface):
        pygame.draw.circle(surface, WHITE, self.pos, self.radius)

    def update(self, dt):
        self.pos += self.vel * dt
        self.pos.x %= SCREEN_WIDTH
        self.pos.y %= SCREEN_HEIGHT

class Asteroid:
    def __init__(self, pos, size):
        self.pos = pygame.Vector2(pos)
        max_vel = 100 * SCALE_FACTOR
        self.vel = pygame.Vector2(random.uniform(-max_vel, max_vel), random.uniform(-max_vel, max_vel))
        if self.vel.length() == 0:
            self.vel = pygame.Vector2(50 * SCALE_FACTOR, 50 * SCALE_FACTOR)
        self.size = size
        self.radius = size * 10 * SCALE_FACTOR
        self.angle = 0
        self.rotation_speed = random.uniform(-60, 60)
        self.shape = []
        num_vertices = random.randint(7, 12)
        for i in range(num_vertices):
            angle = (i / num_vertices) * 2 * math.pi
            radius = self.radius + random.uniform(-self.radius/4, self.radius/4)
            self.shape.append(pygame.Vector2(radius * math.cos(angle), radius * math.sin(angle)))

    def draw(self, surface):
        points = []
        for point in self.shape:
            rotated_point = point.rotate(self.angle)
            points.append(self.pos + rotated_point)
        pygame.draw.polygon(surface, WHITE, points, 2)

    def update(self, dt):
        self.pos += self.vel * dt
        self.angle += self.rotation_speed * dt
        self.pos.x %= SCREEN_WIDTH
        self.pos.y %= SCREEN_HEIGHT
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
